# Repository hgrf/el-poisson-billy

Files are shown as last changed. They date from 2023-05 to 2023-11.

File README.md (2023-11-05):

# El Poisson Billy

El Poisson is yet another hacked Big Mouth Billy Bass. It was a little contribution to Moorea's 2023
music video "[Un effort](https://www.youtube.com/watch?v=xZalNH8_v24)". This particular hack
features a Bluetooth audio sink and motor control via bluetooth. The python GUI is easy to use and
can even connect to Ableton via a virtual MIDI interface, so that the fish's movements can be
programmed as a MIDI track.

## Features

- ESP32 configured as bluetooth audio sink with additional serial port profile (SPP) for control.
- Teensy Audio Shield Rev D for high-quality audio output.
- H-bridge L293D for efficient motor control.
- Python GUI for easy interaction with the device.

## Hardware

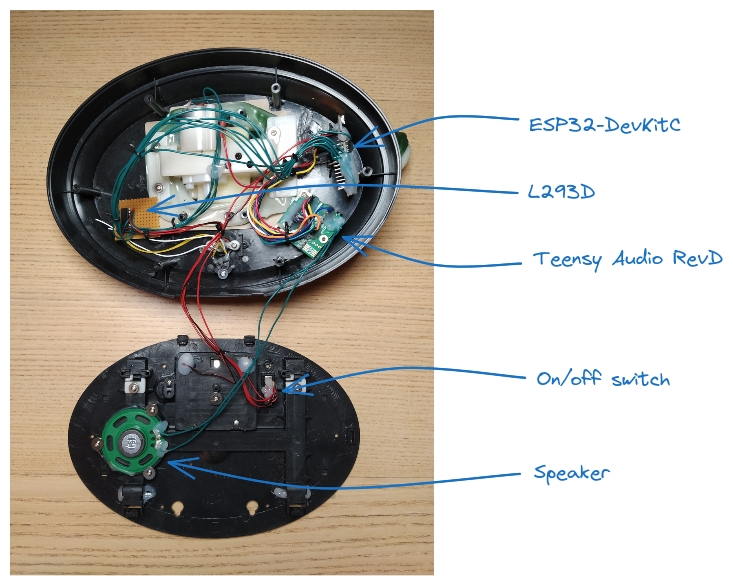
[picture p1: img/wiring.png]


### Components

- Billy the Bass
- ESP32-DevKitC (https://www.espressif.com/en/products/devkits/esp32-devkitc/overview)
- Teensy Audio Shield Rev D (https://www.pjrc.com/store/teensy3_audio.html)
- H-bridge L293D (https://www.st.com/en/motor-drivers/l293d.html)

### Schematic



## Software

### Python GUI

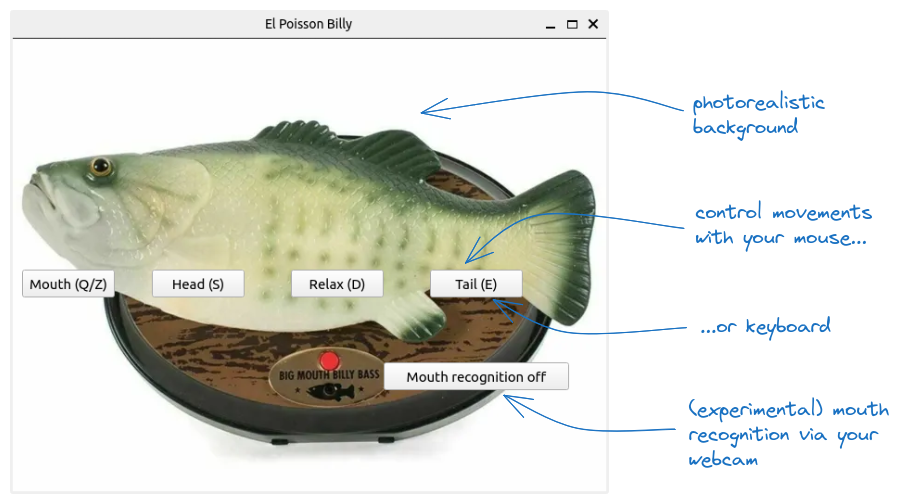
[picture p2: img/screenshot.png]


You can set up the python app with:

```sh
python3 -m venv venv
. venv/bin/activate
python -m pip install --upgrade pip
pip install -r requirements.txt

python -m gui
```

### Firmware

The firmware is based on the following examples from ESP-IDF:

- https://github.com/espressif/esp-idf/tree/v5.1.1/examples/bluetooth/bluedroid/classic_bt/a2dp_sink
- https://github.com/espressif/esp-idf/blob/v5.1.1/examples/bluetooth/bluedroid/classic_bt/bt_spp_acceptor

Please use ESP-IDF v5.1.1 to build the firmware.

To flash a binary release, use (for example):

```sh
pip install esptool==4.6.2
esptool.py write_flash 0x10000 el-poisson-billy-0.1.0.bin
```

## References

### Other Billy Bass projects

- https://maker.pro/arduino/projects/how-to-animate-billy-bass-with-bluetooth-audio-source
- https://www.instructables.com/Animate-a-Billy-Bass-Mouth-With-Any-Audio-Source/
- https://www.hackster.io/news/this-mod-turns-big-mouth-billy-bass-into-an-arduino-controlled-platform-for-shenanigans-cac985a04b47
- https://os.mbed.com/cookbook/Big-Mouth-Billy-Bass
- https://gist.github.com/jamesbulpin/f3b20833ab0bf035ae8fd3a69405b222
- https://github.com/TensorFlux/BTBillyBass

### Mouth synchronization

- https://mittalparveen652.medium.com/face-eye-and-mouth-detection-with-python-458f2a028674
- https://hackprojects.wordpress.com/tutorials/opencv-python-tutorials/opencv-mouth-detection-using-haar-cascades/
- https://github.com/mauckc/mouth-open
- https://github.com/opencv/opencv/tree/master/data/haarcascades
- https://github.com/peterbraden/node-opencv/blob/master/data/haarcascade_mcs_mouth.xml
- https://github.com/DanielSWolf/rhubarb-lip-sync

### Others

- PyQt and OpenCV: https://gist.github.com/docPhil99/ca4da12c9d6f29b9cea137b617c7b8b1

### KiCad symbols and footprints

- ESP32-DevKitC: https://github.com/espressif/kicad-libraries
- Teensy Audio Shield Rev D: https://forum.pjrc.com/threads/65435

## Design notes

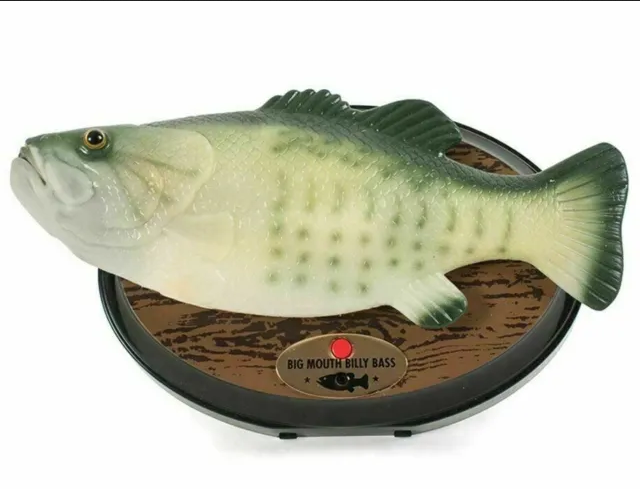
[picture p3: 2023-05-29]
img/poisson.png

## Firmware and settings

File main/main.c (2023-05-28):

/*
 * SPDX-FileCopyrightText: 2021-2022 Espressif Systems (Shanghai) CO LTD
 *
 * SPDX-License-Identifier: Unlicense OR CC0-1.0
 */

#include <stdio.h>
#include <stdlib.h>
#include <unistd.h>
#include <string.h>
#include <inttypes.h>
#include "freertos/FreeRTOS.h"
#include "freertos/task.h"
#include "nvs.h"
#include "nvs_flash.h"
#include "esp_system.h"
#include "esp_log.h"

#include "esp_bt.h"
#include "bt_app_core.h"
#include "bt_app_av.h"
#include "esp_bt_main.h"
#include "esp_bt_device.h"
#include "esp_gap_bt_api.h"
#include "esp_a2dp_api.h"
#include "esp_avrc_api.h"

#include "driver/ledc.h"
#include "driver/i2c.h"

#include "sgtl5000.h"
#include "body.h"
#include "bt_app_spp.h"

#define MCLK_FREQ               (11289600)

/* device name */
#define LOCAL_DEVICE_NAME    "El Poisson"

static const esp_spp_mode_t esp_spp_mode = ESP_SPP_MODE_CB;
static const bool esp_spp_enable_l2cap_ertm = true;

/* event for stack up */
enum {
    BT_APP_EVT_STACK_UP = 0,
};

/********************************
 * STATIC FUNCTION DECLARATIONS
 *******************************/

/* GAP callback function */
static void bt_app_gap_cb(esp_bt_gap_cb_event_t event, esp_bt_gap_cb_param_t *param);
/* handler for bluetooth stack enabled events */
static void bt_av_hdl_stack_evt(uint16_t event, void *p_param);

/*******************************
 * STATIC FUNCTION DEFINITIONS
 ******************************/

static void bt_app_gap_cb(esp_bt_gap_cb_event_t event, esp_bt_gap_cb_param_t *param)
{
    uint8_t *bda = NULL;

    switch (event) {
    /* when authentication completed, this event comes */
    case ESP_BT_GAP_AUTH_CMPL_EVT: {
        if (param->auth_cmpl.stat == ESP_BT_STATUS_SUCCESS) {
            ESP_LOGI(BT_AV_TAG, "authentication success: %s", param->auth_cmpl.device_name);
            esp_log_buffer_hex(BT_AV_TAG, param->auth_cmpl.bda, ESP_BD_ADDR_LEN);
        } else {
            ESP_LOGE(BT_AV_TAG, "authentication failed, status: %d", param->auth_cmpl.stat);
        }
        break;
    }

#if (CONFIG_BT_SSP_ENABLED == true)
    /* when Security Simple Pairing user confirmation requested, this event comes */
    case ESP_BT_GAP_CFM_REQ_EVT:
        ESP_LOGI(BT_AV_TAG, "ESP_BT_GAP_CFM_REQ_EVT Please compare the numeric value: %"PRIu32, param->cfm_req.num_val);
        esp_bt_gap_ssp_confirm_reply(param->cfm_req.bda, true);
        break;
    /* when Security Simple Pairing passkey notified, this event comes */
    case ESP_BT_GAP_KEY_NOTIF_EVT:
        ESP_LOGI(BT_AV_TAG, "ESP_BT_GAP_KEY_NOTIF_EVT passkey: %"PRIu32, param->key_notif.passkey);
        break;
    /* when Security Simple Pairing passkey requested, this event comes */
    case ESP_BT_GAP_KEY_REQ_EVT:
        ESP_LOGI(BT_AV_TAG, "ESP_BT_GAP_KEY_REQ_EVT Please enter passkey!");
        break;
#endif

    /* when GAP mode changed, this event comes */
    case ESP_BT_GAP_MODE_CHG_EVT:
        ESP_LOGI(BT_AV_TAG, "ESP_BT_GAP_MODE_CHG_EVT mode: %d", param->mode_chg.mode);
        break;
    /* when ACL connection completed, this event comes */
    case ESP_BT_GAP_ACL_CONN_CMPL_STAT_EVT:
        bda = (uint8_t *)param->acl_conn_cmpl_stat.bda;
        ESP_LOGI(BT_AV_TAG, "ESP_BT_GAP_ACL_CONN_CMPL_STAT_EVT Connected to [%02x:%02x:%02x:%02x:%02x:%02x], status: 0x%x",
                 bda[0], bda[1], bda[2], bda[3], bda[4], bda[5], param->acl_conn_cmpl_stat.stat);
        break;
    /* when ACL disconnection completed, this event comes */
    case ESP_BT_GAP_ACL_DISCONN_CMPL_STAT_EVT:
        bda = (uint8_t *)param->acl_disconn_cmpl_stat.bda;
        ESP_LOGI(BT_AV_TAG, "ESP_BT_GAP_ACL_DISC_CMPL_STAT_EVT Disconnected from [%02x:%02x:%02x:%02x:%02x:%02x], reason: 0x%x",
                 bda[0], bda[1], bda[2], bda[3], bda[4], bda[5], param->acl_disconn_cmpl_stat.reason);
        break;
    /* others */
    default: {
        ESP_LOGI(BT_AV_TAG, "event: %d", event);
        break;
    }
    }
}

static void bt_av_hdl_stack_evt(uint16_t event, void *p_param)
{
    ESP_LOGD(BT_AV_TAG, "%s event: %d", __func__, event);

    switch (event) {
    /* when do the stack up, this event comes */
    case BT_APP_EVT_STACK_UP: {
        esp_bt_dev_set_device_name(LOCAL_DEVICE_NAME);

        assert(esp_spp_register_callback(esp_spp_cb) == ESP_OK);

        esp_spp_cfg_t bt_spp_cfg = {
            .mode = esp_spp_mode,
            .enable_l2cap_ertm = esp_spp_enable_l2cap_ertm,
            .tx_buffer_size = 0, /* Only used for ESP_SPP_MODE_VFS mode */
        };
        assert(esp_spp_enhanced_init(&bt_spp_cfg) == ESP_OK);

        esp_bt_gap_register_callback(bt_app_gap_cb);

        assert(esp_avrc_ct_init() == ESP_OK);
        esp_avrc_ct_register_callback(bt_app_rc_ct_cb);
        assert(esp_avrc_tg_init() == ESP_OK);
        esp_avrc_tg_register_callback(bt_app_rc_tg_cb);

        esp_avrc_rn_evt_cap_mask_t evt_set = {0};
        esp_avrc_rn_evt_bit_mask_operation(ESP_AVRC_BIT_MASK_OP_SET, &evt_set, ESP_AVRC_RN_VOLUME_CHANGE);
        assert(esp_avrc_tg_set_rn_evt_cap(&evt_set) == ESP_OK);

        assert(esp_a2d_sink_init() == ESP_OK);
        esp_a2d_register_callback(&bt_app_a2d_cb);
        esp_a2d_sink_register_data_callback(bt_app_a2d_data_cb);

        /* Get the default value of the delay value */
        esp_a2d_sink_get_delay_value();

        /* set discoverable and connectable mode, wait to be connected */
        esp_bt_gap_set_scan_mode(ESP_BT_CONNECTABLE, ESP_BT_GENERAL_DISCOVERABLE);
        break;
    }
    /* others */
    default:
        ESP_LOGE(BT_AV_TAG, "%s unhandled event: %d", __func__, event);
        break;
    }
}

/*******************************
 * MAIN ENTRY POINT
 ******************************/

void app_main(void)
{
    /* initialize NVS — it is used to store PHY calibration data */
    esp_err_t err = nvs_flash_init();
    if (err == ESP_ERR_NVS_NO_FREE_PAGES || err == ESP_ERR_NVS_NEW_VERSION_FOUND) {
        ESP_ERROR_CHECK(nvs_flash_erase());
        err = nvs_flash_init();
    }
    ESP_ERROR_CHECK(err);

    /* set up body */
    body_init();

    /* set up I2C bus */
    i2c_port_t i2c_master_port = 1;
    i2c_config_t conf = {
        .mode = I2C_MODE_MASTER,
        .sda_io_num = 13,
        .sda_pullup_en = GPIO_PULLUP_ENABLE,        /* From I2C driver datasheet; internal pull-up may not be sufficient */
        .scl_io_num = 4,
        .scl_pullup_en = GPIO_PULLUP_ENABLE,
        .master = {
            .clk_speed = 100000
        }
    };
    ESP_ERROR_CHECK(i2c_param_config(i2c_master_port, &conf));
    ESP_ERROR_CHECK(i2c_driver_install(i2c_master_port, conf.mode, 0, 0, 0));

    /* set up MCLK signal */
    ledc_timer_config_t ledc_timer = {
        .duty_resolution = LEDC_TIMER_2_BIT,
        .freq_hz = MCLK_FREQ,
        .speed_mode = LEDC_HIGH_SPEED_MODE,
        .timer_num = LEDC_TIMER_0
    };
    ledc_timer_config(&ledc_timer);

    ledc_channel_config_t ledc_channel = {
        .channel = LEDC_CHANNEL_0,
        .duty = 2,
        .gpio_num = 15,
        .speed_mode = LEDC_HIGH_SPEED_MODE,
        .hpoint = 0,
        .timer_sel = LEDC_TIMER_0
    };
    ledc_channel_config(&ledc_channel);

    vTaskDelay(500 / portTICK_PERIOD_MS);

    /* initialize audio codec */
    sgtl5000_init(i2c_master_port, 0b0001010);

    /*
     * This example only uses the functions of Classical Bluetooth.
     * So release the controller memory for Bluetooth Low Energy.
     */
    ESP_ERROR_CHECK(esp_bt_controller_mem_release(ESP_BT_MODE_BLE));

    esp_bt_controller_config_t bt_cfg = BT_CONTROLLER_INIT_CONFIG_DEFAULT();
    if ((err = esp_bt_controller_init(&bt_cfg)) != ESP_OK) {
        ESP_LOGE(BT_AV_TAG, "%s initialize controller failed: %s\n", __func__, esp_err_to_name(err));
        return;
    }
    if ((err = esp_bt_controller_enable(ESP_BT_MODE_CLASSIC_BT)) != ESP_OK) {
        ESP_LOGE(BT_AV_TAG, "%s enable controller failed: %s\n", __func__, esp_err_to_name(err));
        return;
    }
    if ((err = esp_bluedroid_init()) != ESP_OK) {
        ESP_LOGE(BT_AV_TAG, "%s initialize bluedroid failed: %s\n", __func__, esp_err_to_name(err));
        return;
    }
    if ((err = esp_bluedroid_enable()) != ESP_OK) {
        ESP_LOGE(BT_AV_TAG, "%s enable bluedroid failed: %s\n", __func__, esp_err_to_name(err));
        return;
    }

#if (CONFIG_BT_SSP_ENABLED == true)
    /* set default parameters for Secure Simple Pairing */
    esp_bt_sp_param_t param_type = ESP_BT_SP_IOCAP_MODE;
    esp_bt_io_cap_t iocap = ESP_BT_IO_CAP_IO;
    esp_bt_gap_set_security_param(param_type, &iocap, sizeof(uint8_t));
#endif

    /* set default parameters for Legacy Pairing (use fixed pin code 1234) */
    esp_bt_pin_type_t pin_type = ESP_BT_PIN_TYPE_FIXED;
    esp_bt_pin_code_t pin_code;
    pin_code[0] = '1';
    pin_code[1] = '2';
    pin_code[2] = '3';
    pin_code[3] = '4';
    esp_bt_gap_set_pin(pin_type, 4, pin_code);

    bt_app_task_start_up();
    /* bluetooth device name, connection mode and profile set up */
    bt_app_work_dispatch(bt_av_hdl_stack_evt, BT_APP_EVT_STACK_UP, NULL, 0, NULL);
}

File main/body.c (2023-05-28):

#include "driver/gpio.h"

#define MOUTH_ENABLE GPIO_NUM_5
#define MOUTH_DIRA GPIO_NUM_18
#define MOUTH_DIRB GPIO_NUM_19

#define BODY_ENABLE GPIO_NUM_21
#define BODY_DIRA GPIO_NUM_22
#define BODY_DIRB GPIO_NUM_23

void body_init()
{
    gpio_set_direction(MOUTH_ENABLE, GPIO_MODE_OUTPUT);
    gpio_set_direction(MOUTH_DIRA, GPIO_MODE_OUTPUT);
    gpio_set_direction(MOUTH_DIRB, GPIO_MODE_OUTPUT);
    
    gpio_set_direction(BODY_ENABLE, GPIO_MODE_OUTPUT);
    gpio_set_direction(BODY_DIRA, GPIO_MODE_OUTPUT);
    gpio_set_direction(BODY_DIRB, GPIO_MODE_OUTPUT);

    /* mouth only opens, closing is done by spring */
    gpio_set_level(MOUTH_DIRA, 1);
    gpio_set_level(MOUTH_DIRB, 0);

    gpio_set_level(MOUTH_ENABLE, 0);
    gpio_set_level(BODY_ENABLE, 0);
}

void body_open_mouth()
{
    gpio_set_level(MOUTH_ENABLE, 1);
}

void body_close_mouth()
{
    gpio_set_level(MOUTH_ENABLE, 0);
}

void body_wiggle_head()
{
    gpio_set_level(BODY_DIRA, 1);
    gpio_set_level(BODY_DIRB, 0);
    gpio_set_level(BODY_ENABLE, 1);
}

void body_wiggle_tail()
{
    gpio_set_level(BODY_DIRA, 0);
    gpio_set_level(BODY_DIRB, 1);
    gpio_set_level(BODY_ENABLE, 1);
}

void body_wiggle_stop()
{
    gpio_set_level(BODY_ENABLE, 0);
}

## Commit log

2023-05-28 add codec driver as submodule
2023-05-28 change device name
2023-11-04 add custom partition table for bigger app
    [partitions.csv]
2023-11-04 add button to start and stop mouth recognition
2023-11-04 add schematic, update README
    [el_poisson_billy_rev1.kicad_sch]
2023-11-04 crop circuit diagram
2023-11-04 join thread on close event
2023-11-04 platform-specific bluetooth socket hack
2023-11-05 add annotated photo of wiring
